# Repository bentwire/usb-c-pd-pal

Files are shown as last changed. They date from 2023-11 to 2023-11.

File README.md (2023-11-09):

# usb-c-pd-pal
100W USB C PD Power path with on board switches and current sensing.  Can take input from USB-C, Barell, or wire terminal, and output to wire terminal or USB-C.

This design can do up to 100W PD.  The switches and connectors are all rated for 5A, the max voltage is 21V so it can't do the extended power ranges.

There is a separate power path for both the 5V only and High Power paths.  The board is wired to be capable of both sink and source modes.

If you wish to make this board act as a source you will need to provide 5V to the 5V power path at the very least.

TODO:
Code forthcoming.
Still need to finish the layout.
Some parts won't be generally available until next year...

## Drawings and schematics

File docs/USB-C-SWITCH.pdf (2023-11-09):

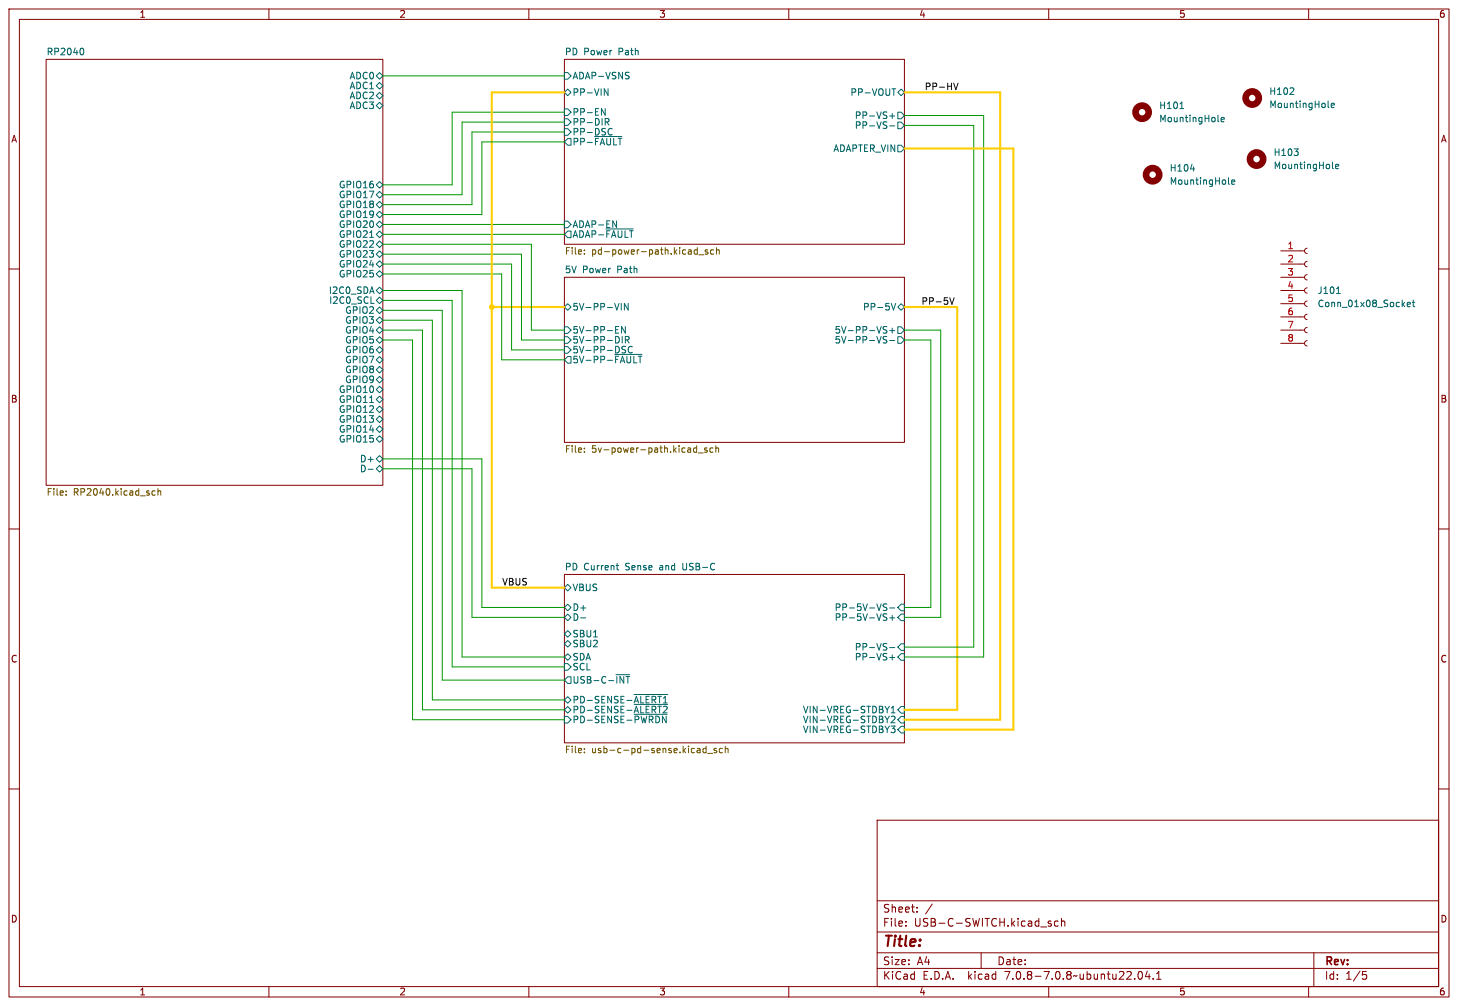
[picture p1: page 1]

PD Power Path File: pd-power-path.kicad_sch

ADAP-VSNS
PP-VOUT PP-VS+ PP-VS- PP-EN

PP-~{FAULT} PP-VIN

PP-DIR
ADAP-~{FAULT} PP-DSC

5V-PP-VS- 5V-PP-VIN

Id: 1/5 Title: File: USB-C-SWITCH.kicad_sch Sheet: / D- D+ GPIO10 GPIO9 GPIO8

File: usb-c-pd-sense.kicad_sch

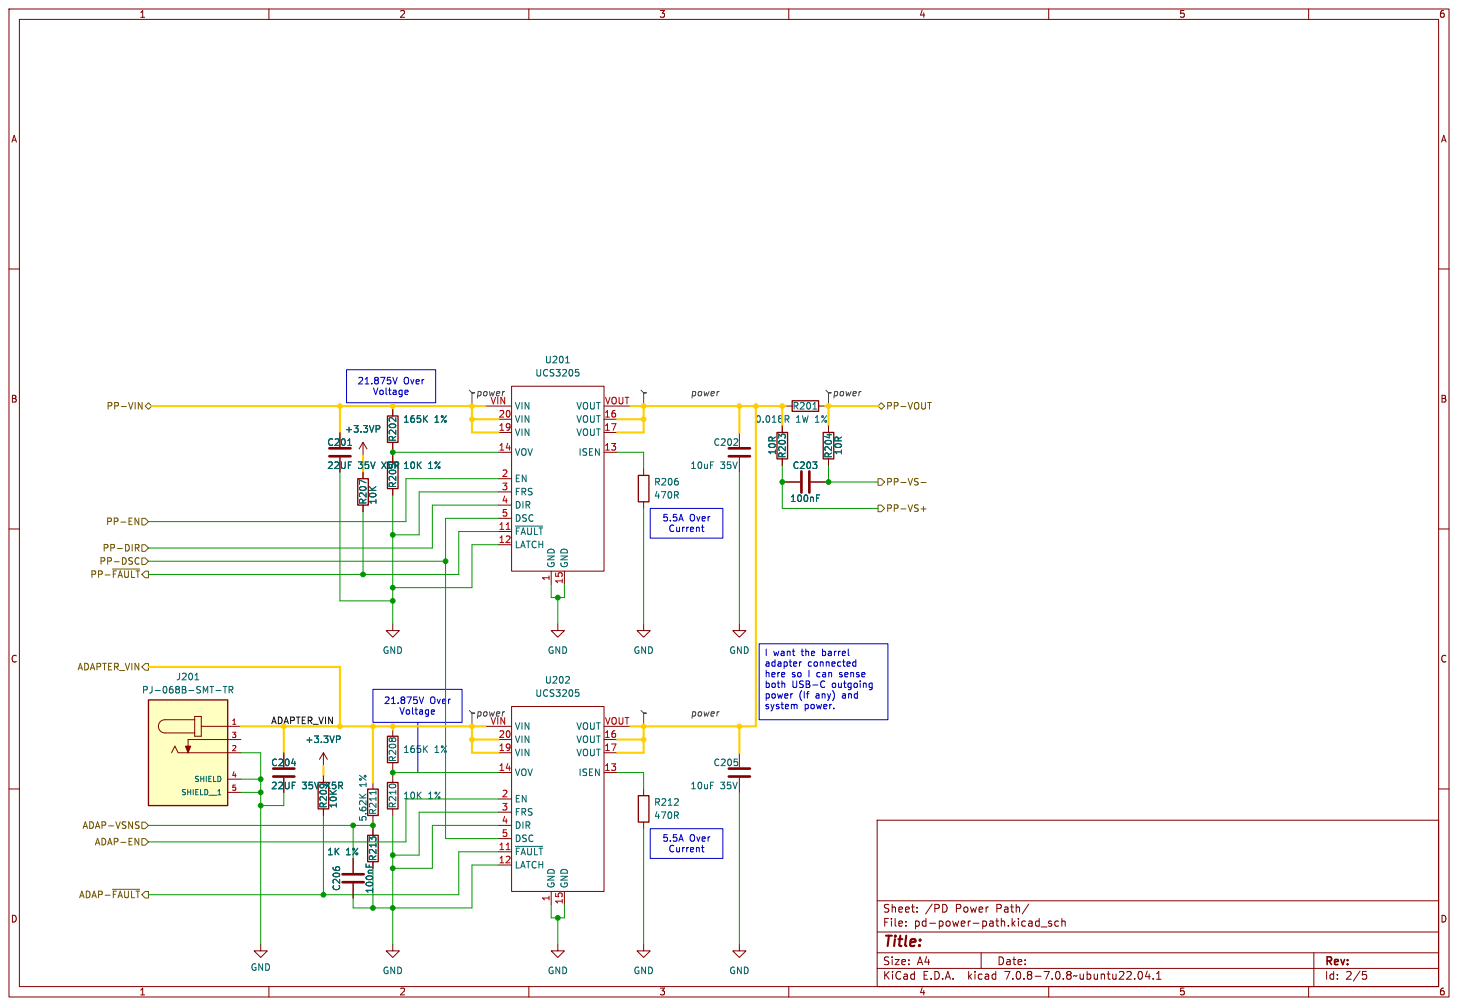
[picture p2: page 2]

system power. 21.875V Over Voltage

I want the barrel adapter connected

here so I can sense
both USB-C outgoing
power (If any) and

ADAP-VSNS
ADAP-~{FAULT} ADAP-EN

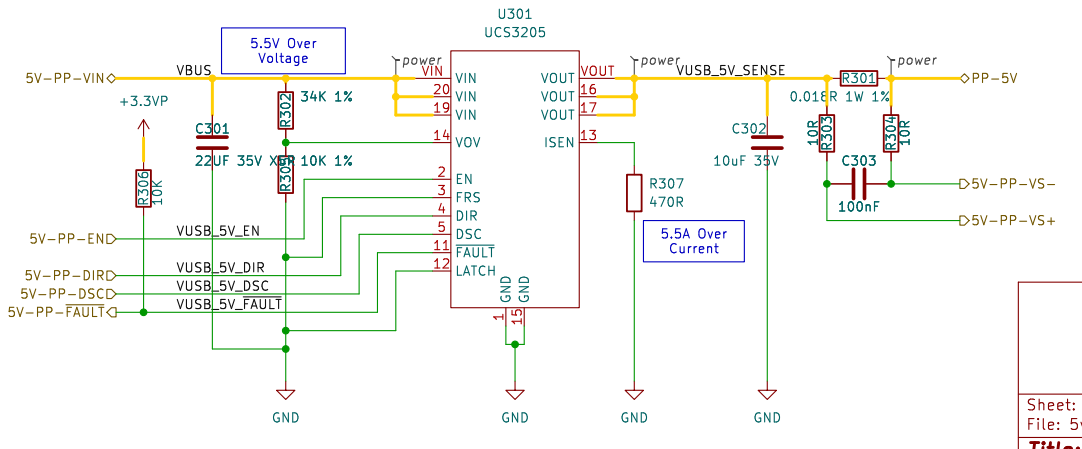
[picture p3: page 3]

5V-PP-~{FAULT} 5V-PP-EN

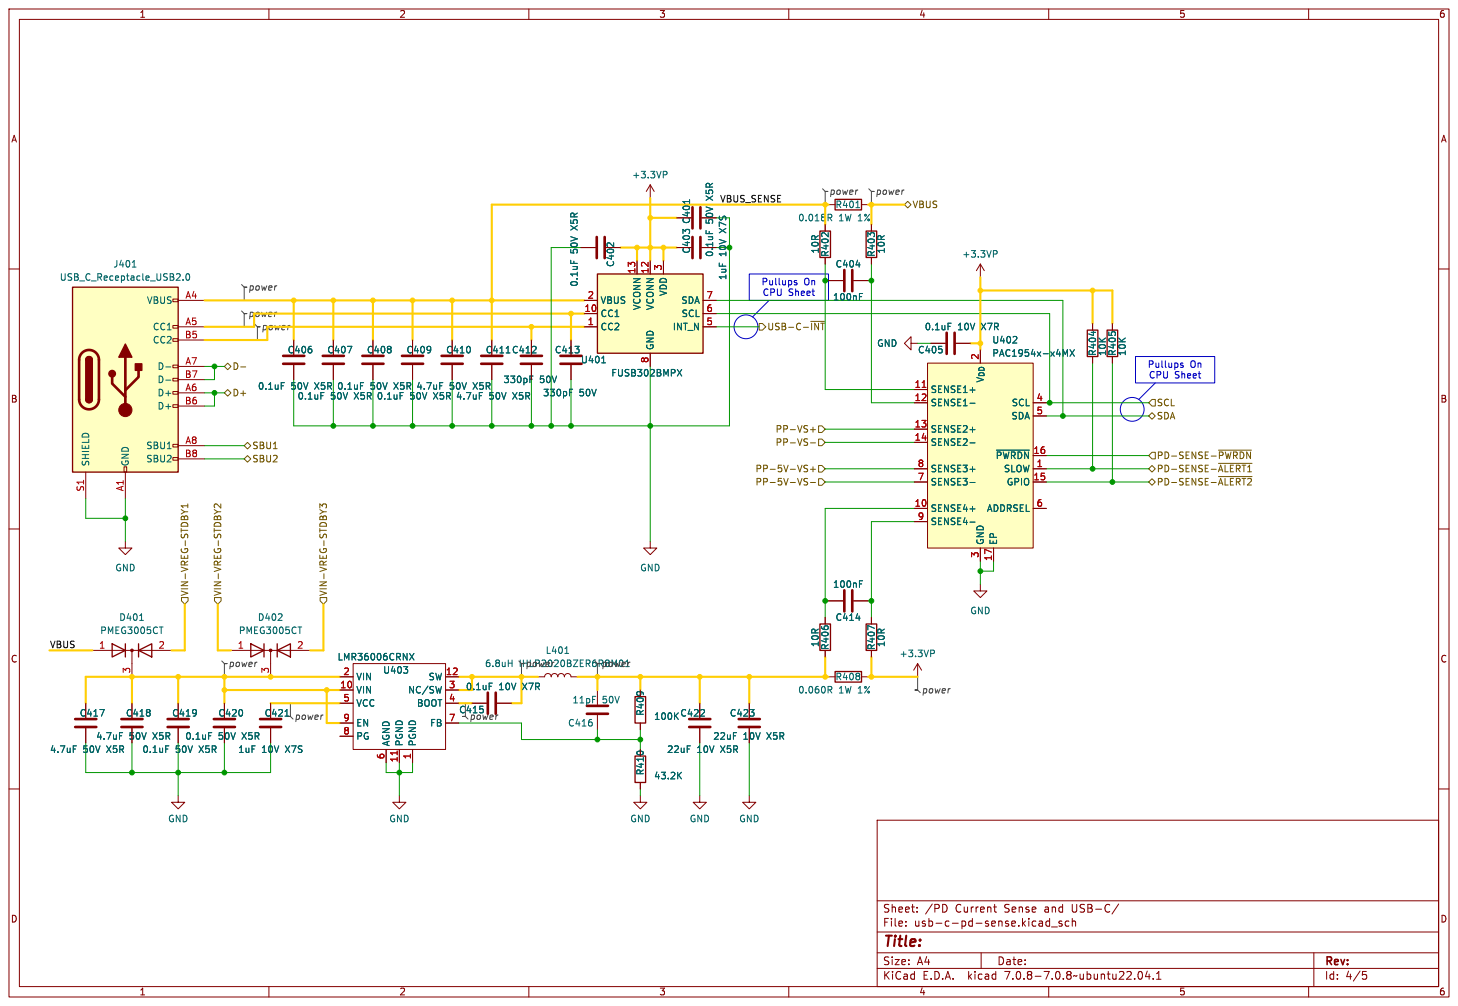
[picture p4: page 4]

3 D402 PMEG3005CT C401 0.1uF 50V X5R R402 10R
power power powerpower power power

Pullups On CPU Sheet Pullups On CPU Sheet C421

3 SCL 4 SDA 5 ADDRSEL 6 SENSE3- 7 SENSE3+ 8 SENSE4- 9 U402 PAC1954x-x4MX GND A1 VBUS A4 CC1 A5 D+ A6 D- A7 SBU1 A8 CC2 B5 D+ B6 D- B7 SBU2 B8 SHIELD S1

1 VIN 10 PGND 11 SW 12 VIN 2 NC/SW 3 BOOT 4 VCC 5 AGND

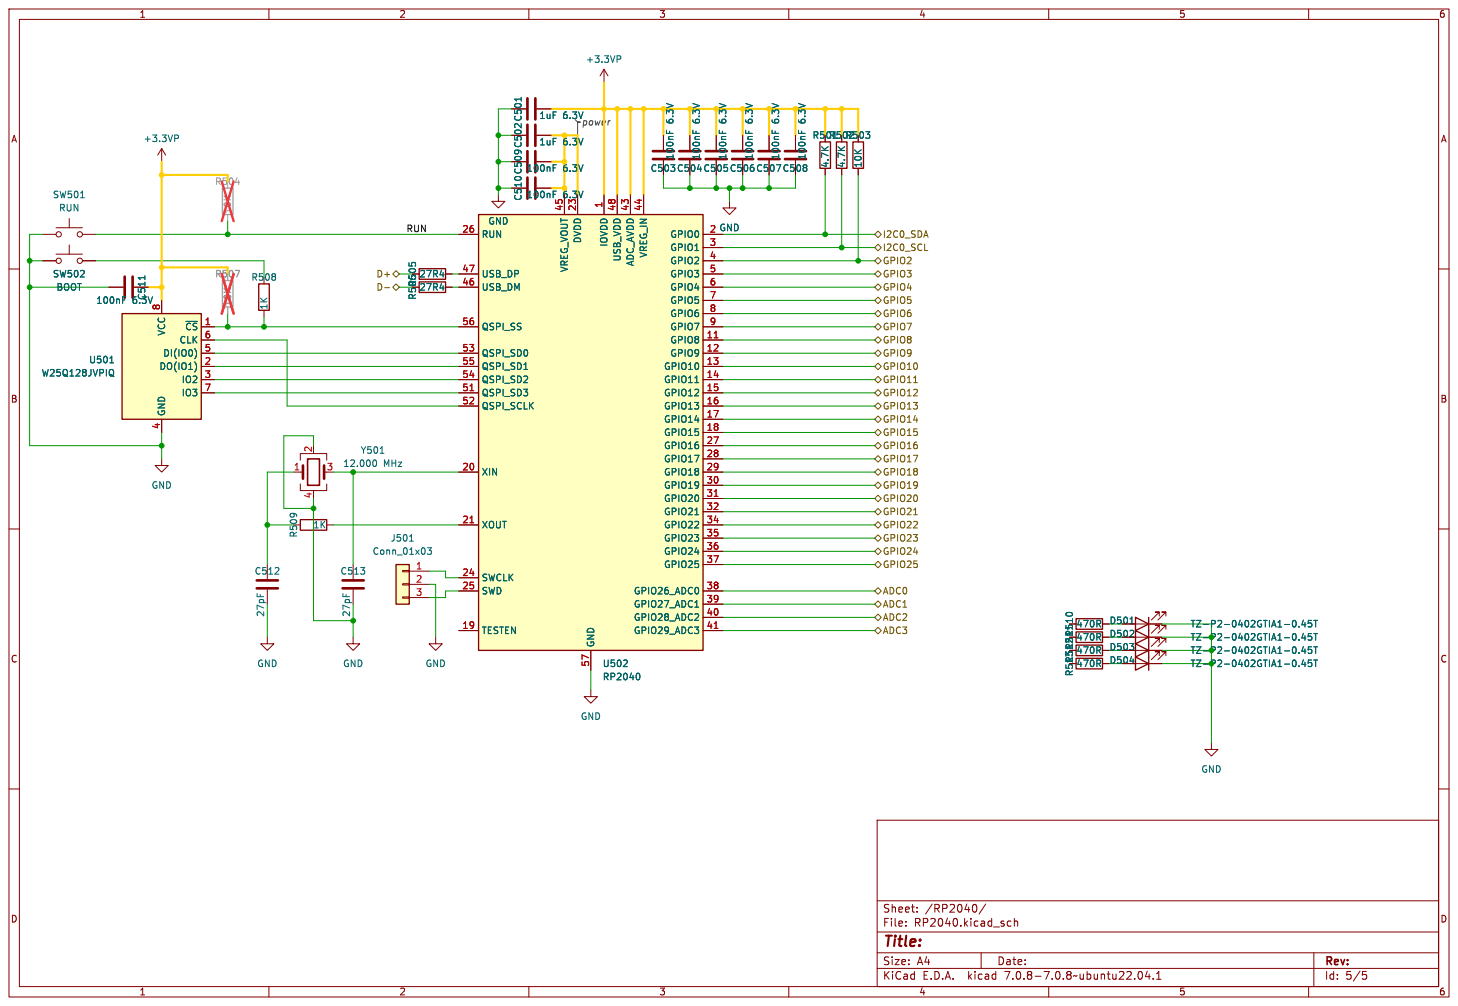
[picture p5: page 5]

1 GPIO8 11 GPIO9 12 GPIO10 13 GPIO11 14 GPIO12 15 GPIO13 16 GPIO14 17 GPIO15 18 TESTEN 19 GPIO0 2 XIN 20 XOUT 21 DVDD 23 SWCLK 24 SWD 25 RUN 26 GPIO16 27 GPIO17 28 GPIO18 29 GPIO1 3 GPIO19 30 GPIO20 31 GPIO21 32 GPIO22 34 GPIO23 35 GPIO24 36 GPIO25 37 GPIO26_ADC0 38 GPIO27_ADC1 39 GPIO2 4 GPIO28_ADC2 40 GPIO29_ADC3 41 ADC_AVDD 43 VREG_IN 44 VREG_VOUT 45 USB_DM 46 USB_DP 47 USB_VDD 48 GPIO3 5 QSPI_SD3 51 QSPI_SCLK 52 QSPI_SD0 53 QSPI_SD2 54 QSPI_SD1 55 QSPI_SS 56 GND 57 GPIO4 6 GPIO5 7 GPIO6 8 GPIO7 9C505 100nF C501 6.3V 1uF 6.3V C503 100nF 6.3V C504 100nF 6.3V R513 470R R511 470R R512 470R R510 470R

1 GPIO8 11 GPIO9 12 GPIO10 13 GPIO11 14 GPIO12 15 GPIO13 16 GPIO14 17 GPIO15 18 TESTEN 19 GPIO0 2 XIN 20 XOUT 21 DVDD 23 SWCLK 24 SWD 25 RUN 26 GPIO16 27 GPIO17 28 GPIO18 29 GPIO1 3 GPIO19 30 GPIO20 31 GPIO21 32 GPIO22 34 GPIO23 35 GPIO24 36 GPIO25 37 GPIO26_ADC0 38 GPIO27_ADC1 39 GPIO2 4 GPIO28_ADC2 40 GPIO29_ADC3 41 ADC_AVDD 43 VREG_IN 44 VREG_VOUT 45 USB_DM 46 USB_DP 47 USB_VDD 48 GPIO3 5 QSPI_SD3 51 QSPI_SCLK 52 QSPI_SD0 53 QSPI_SD2 54 QSPI_SD1 55 QSPI_SS 56 GND 57 GPIO4 6 GPIO5 7 GPIO6 8 GPIO7 9 U502 RP2040 GND

Id: 5/5 Title: File: RP2040.kicad_sch Sheet: /RP2040/

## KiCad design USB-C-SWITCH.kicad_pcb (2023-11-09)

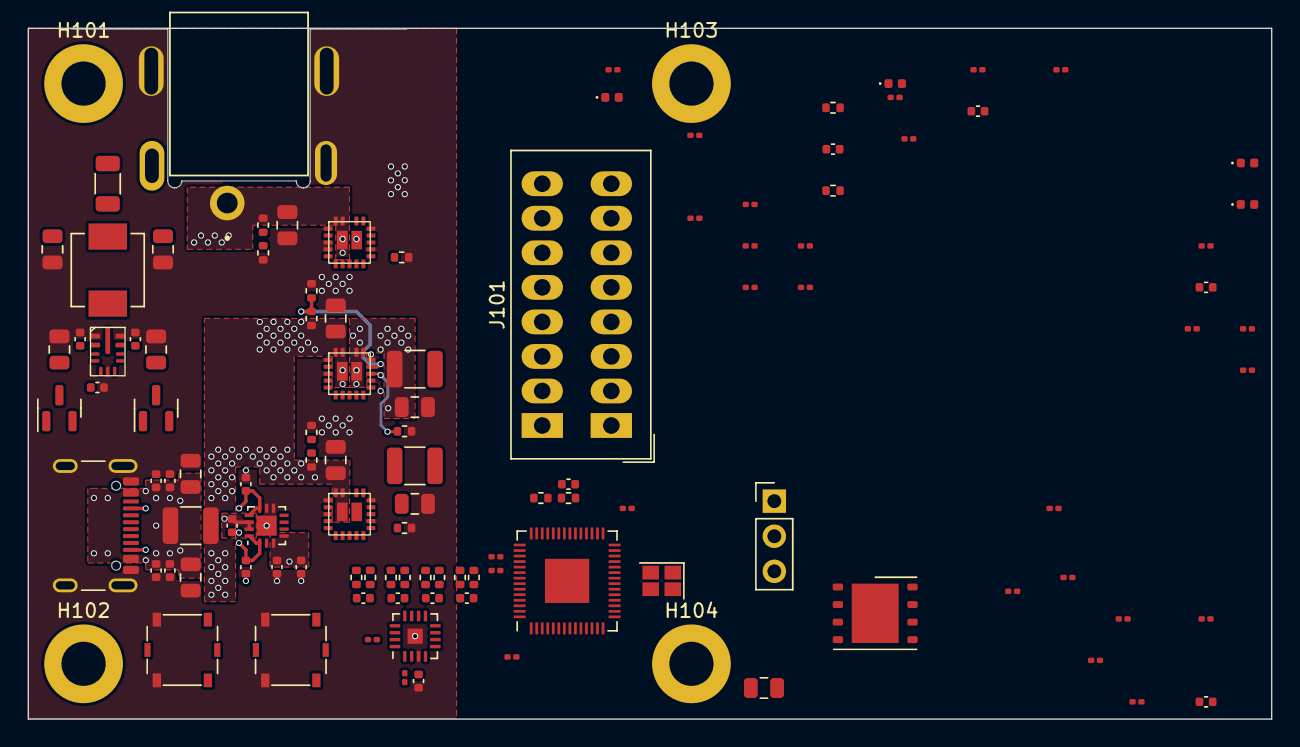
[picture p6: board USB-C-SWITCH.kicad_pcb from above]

Board: 4 copper layers, 90.0 x 50.0 mm, 114 parts (0 on the bottom side), 70 nets.

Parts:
C201, C204, C301: 22UF 35V X5R; C_0805_2012Metric
C202, C205, C302: 10uF 35V; C_0805_2012Metric
C203, C206, C303, C404, C414: 100nF; C_0402_1005Metric
C401, C402, C406, C407, C408, C409, C419, C420: 0.1uF 50V X5R; C_0402_1005Metric
C403, C421: 1uF 10V X7S; C_0402_1005Metric
C405, C415: 0.1uF 10V X7R; C_0402_1005Metric
C410, C411, C417, C418: 4.7uF 50V X5R; C_0805_2012Metric
C412, C413: 330pF 50V; C_0402_1005Metric
C416: 11pF 50V; C_0402_1005Metric
C422, C423: 22uF 10V X5R; C_0805_2012Metric
C501, C502: 1uF 6.3V; C_0402_1005Metric
C503, C504, C505, C506, C507, C508, C509, C510, C511: 100nF 6.3V; C_0201_0603Metric
C512, C513: 27pF; C_0201_0603Metric
D401, D402: PMEG3005CT; SOT-23
D501, D502, D503, D504: TZ-P2-0402GTIA1-0.45T; LED_0402_1005Metric
H101, H102, H103, H104: MountingHole; MountingHole_3.2mm_M3_ISO7380_Pad
J101: Conn_01x08_Socket; TerminalBlock_Phoenix_PTSM-0,5-8-2.5-H-THR_1x08_P2.50mm_Hor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
J201: PJ-068B-SMT-TR; CUI_PJ-068B-SMT-TR
J401: USB_C_Receptacle_USB2.0; USB_C_Receptacle_GCT_USB4105-xx-A_16P_TopMnt_Horizontal
J501: Conn_01x03; PinHeader_1x03_P2.54mm_Vertical
L401: 6.8uH IHLP2020BZER6R8M01; L_Vishay_IHLP-2020
R201, R301, R401: 0.018R 1W 1%; R_1210_3225Metric
R202, R208: 165K 1%; R_0402_1005Metric
R203, R204, R303, R304, R402, R403, R406, R407: 10R; R_0402_1005Metric
R205, R210, R305: 10K 1%; R_0402_1005Metric
R206, R212, R307: 470R; R_0402_1005Metric
R207, R209, R306, R404, R405, R503, R504, R507: 10K; R_0201_0603Metric
R211: 5.62K 1%; R_0402_1005Metric
R213: 1K 1%; R_0402_1005Metric
R302: 34K 1%; R_0402_1005Metric
R408: 0.060R 1W 1%; R_1206_3216Metric
R409: 100K; R_0402_1005Metric
R410: 43.2K; R_0402_1005Metric
R501, R502: 4.7K; R_0201_0603Metric
R505, R506: 27R4; R_0201_0603Metric
R508, R509: 1K; R_0201_0603Metric
R510, R511, R512, R513: 470R; R_0201_0603Metric
SW501: RUN; SW_SPST_Panasonic_EVQPL_3PL_5PL_PT_A15
SW502: BOOT; SW_SPST_Panasonic_EVQPL_3PL_5PL_PT_A15
U201, U202, U301: UCS3205; 19-VQFN-Q8A-3x3x0.9-2EP
U401: FUSB302BMPX; WQFN-14-1EP_2.5x2.5mm_P0.5mm_EP1.45x1.45mm
U402: PAC1954x-x4MX; VQFN-16-1EP_3x3mm_P0.5mm_EP1.1x1.1mm
U403: LMR36006CRNX; TI-RNX0012A-VQFN-HR
U501: W25Q128JVPIQ; WSON-8-1EP_6x5mm_P1.27mm_EP3.4x4.3mm
U502: RP2040; QFN-56-1EP_7x7mm_P0.4mm_EP3.2x3.2mm
Y501: 12.000 MHz; Crystal_SMD_EuroQuartz_X22-4Pin_2.5x2.0mm

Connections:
+3.3VP: C401.1, C402.1, C403.1, C405.2, C501.2, C503.2, C504.2, C505.2, C506.2, C507.2, C508.2, C511.1, R207.1, R209.1, R306.1, R404.1, R405.1, R407.1, R408.2, R501.1, R502.1, R503.1, R504.1, R507.1, U401.3 (VDD), U401.4 (VDD), U401.12 (VCONN), U401.13 (VCONN), U402.2 (V_{DD}), U501.8 (VCC), U502.1 (IOVDD), U502.10 (IOVDD), U502.22 (IOVDD), U502.33 (IOVDD), U502.42 (IOVDD), U502.43 (ADC_AVDD), U502.44 (VREG_IN), U502.48 (USB_VDD), U502.49 (IOVDD)
/5V Power Path/5V-PP-VS+: C303.1, R303.2, U402.8 (SENSE3+)
/5V Power Path/5V-PP-VS-: C303.2, R304.2, U402.7 (SENSE3-)
/5V Power Path/VUSB_5V_DIR: U301.4 (DIR), U502.35 (GPIO23)
/5V Power Path/VUSB_5V_DSC: U301.5 (DSC), U502.36 (GPIO24)
/5V Power Path/VUSB_5V_EN: U301.2 (EN), U502.34 (GPIO22)
/5V Power Path/VUSB_5V_SENSE: C302.1, R301.1, R303.1, U301.16 (VOUT), U301.17 (VOUT), U301.VOUT
/5V Power Path/VUSB_5V_~FAULT: R306.2, U301.11 (~FAULT), U502.37 (GPIO25)
/PD Current Sense and USB-C/D+: J401.A6 (D+), J401.B6 (D+), R505.1
/PD Current Sense and USB-C/D-: J401.A7 (D-), J401.B7 (D-), R506.1
/PD Current Sense and USB-C/PD-SENSE-~ALERT1: R404.2, U402.1 (SLOW), U502.5 (GPIO3)
/PD Current Sense and USB-C/PD-SENSE-~ALERT2: R405.2, U402.15 (GPIO), U502.6 (GPIO4)
/PD Current Sense and USB-C/PD-SENSE-~PWRDN: U402.16 (~PWRDN), U502.7 (GPIO5)
/PD Current Sense and USB-C/PP-VS+: C203.1, R203.2, U402.13 (SENSE2+)
/PD Current Sense and USB-C/PP-VS-: C203.2, R204.2, U402.14 (SENSE2-)
/PD Current Sense and USB-C/SCL: R502.2, U401.6 (SCL), U402.4 (SCL), U502.3 (GPIO1)
/PD Current Sense and USB-C/SDA: R501.2, U401.7 (SDA), U402.5 (SDA), U502.2 (GPIO0)
/PD Current Sense and USB-C/USB-C-~INT: R503.2, U401.5 (INT_N), U502.4 (GPIO2)
/PD Current Sense and USB-C/VBUS_SENSE: C406.1, C407.1, C408.1, C409.1, C410.1, C411.1, J401.A4 (VBUS), J401.A9 (VBUS), J401.B4 (VBUS), J401.B9 (VBUS), R401.1, R402.1, U401.2 (VBUS)
/PD Power Path/ADAP-EN: U202.2 (EN), U502.31 (GPIO20)
/PD Power Path/ADAP-VSNS: C206.2, R211.2, R213.1, U502.38 (GPIO26_ADC0)
/PD Power Path/ADAP-~FAULT: R209.2, U202.11 (~FAULT), U502.32 (GPIO21)
/PD Power Path/ADAPTER_VIN: C204.1, D402.2 (A), J201.1, R208.1, R211.1, U202.19 (VIN), U202.20 (VIN), U202.VIN
/PD Power Path/PP-DIR: U201.4 (DIR), U502.28 (GPIO17)
/PD Power Path/PP-DSC: U201.5 (DSC), U202.5 (DSC), U502.29 (GPIO18)
/PD Power Path/PP-EN: U201.2 (EN), U502.27 (GPIO16)
/PD Power Path/PP-~FAULT: R207.2, U201.11 (~FAULT), U502.30 (GPIO19)
/PP-5V: D401.2 (A), R301.2, R304.1
/PP-HV: D402.1 (A), R201.2, R204.1
/RP2040/RUN: R504.2, SW501.2, U502.26 (RUN)
/VBUS: C201.1, C301.1, D401.1 (A), R202.1, R302.1, R401.2, R403.1, U201.19 (VIN), U201.20 (VIN), U201.VIN, U301.19 (VIN), U301.20 (VIN), U301.VIN
GND: C201.2, C202.2, C204.2, C205.2, C206.1, C301.2, C302.2, C401.2, C402.2, C403.2, C405.1, C406.2, C407.2, C408.2, C409.2, C410.2, C411.2, C412.1, C413.1, C417.2, C418.2, C419.2, C420.2, C421.2, C422.1, C423.1, C501.1, C502.1, C503.1, C504.1, C505.1, C506.1, C507.1, C508.1, C509.1, C510.1, C511.2, C512.2, C513.2, D501.1 (K), D502.1 (K), D503.1 (K), D504.1 (K), J201.2, J201.4 (SHIELD), J201.5 (SHIELD__1), J401.A1 (GND), J401.A12 (GND), J401.B1 (GND), J401.B12 (GND), J401.S1 (SHIELD), J501.2, R205.2, R206.2, R210.2, R212.2, R213.2, R305.2, R307.2, R410.2, SW501.1, SW502.1, U201.1 (GND), U201.3 (FRS), U201.12 (LATCH), U201.15 (GND), U202.1 (GND), U202.3 (FRS), U202.4 (DIR), U202.12 (LATCH), U202.15 (GND), U301.1 (GND), U301.3 (FRS), U301.12 (LATCH), U301.15 (GND), U401.8 (GND), U401.9 (GND), U401.15 (GND), U402.3 (GND), U402.17 (EP), U403.1 (PGND), U403.6 (AGND), U403.11 (PGND), U501.4 (GND), U502.57 (GND), Y501.2, Y501.4
unnamed: C202.1, C205.1, R201.1, R203.1, U201.16 (VOUT), U201.17 (VOUT), U201.VOUT, U202.16 (VOUT), U202.17 (VOUT), U202.VOUT
unnamed: C416.2, C422.2, C423.2, L401.2, R406.1, R408.1, R409.1
unnamed: C512.1, R509.1, Y501.1
unnamed: C417.1, C418.1, C419.1, C420.1, D401.3 (K), D402.3 (K), U403.2 (VIN), U403.9 (EN), U403.10 (VIN)
unnamed: D501.2 (A), R510.2
unnamed: D502.2 (A), R511.2
unnamed: D503.2 (A), R512.2
unnamed: D504.2 (A), R513.2
unnamed: C413.2, J401.A5 (CC1), U401.10 (CC1), U401.11 (CC1)
unnamed: C412.2, J401.B5 (CC2), U401.1 (CC2), U401.14 (CC2)
unnamed: J501.1, U502.24 (SWCLK)
unnamed: J501.3, U502.25 (SWD)
unnamed: R508.1, SW502.2
unnamed: R206.1, U201.13 (ISEN)
unnamed: R202.2, R205.1, U201.14 (VOV)
unnamed: R212.1, U202.13 (ISEN)
unnamed: R208.2, R210.1, U202.14 (VOV)
unnamed: R307.1, U301.13 (ISEN)
unnamed: R302.2, R305.1, U301.14 (VOV)
unnamed: C404.1, R402.2, U402.11 (SENSE1+)
unnamed: C404.2, R403.2, U402.12 (SENSE1-)
unnamed: C414.1, R406.2, U402.10 (SENSE4+)
unnamed: C414.2, R407.2, U402.9 (SENSE4-)
unnamed: C415.1, U403.4 (BOOT)
unnamed: C416.1, R409.2, R410.1, U403.7 (FB)
unnamed: C415.2, L401.1, U403.3 (NC/SW), U403.12 (SW)
unnamed: C421.1, U403.5 (VCC)
unnamed: U501.6 (CLK), U502.52 (QSPI_SCLK)
unnamed: U501.5 (DI(IO0)), U502.53 (QSPI_SD0)
unnamed: U501.2 (DO(IO1)), U502.55 (QSPI_SD1)
unnamed: U501.3 (IO2), U502.54 (QSPI_SD2)
unnamed: U501.7 (IO3), U502.51 (QSPI_SD3)
unnamed: R507.2, R508.2, U501.1 (~CS), U502.56 (QSPI_SS)
unnamed: R506.2, U502.46 (USB_DM)
unnamed: R505.2, U502.47 (USB_DP)
unnamed: C502.2, C509.2, C510.2, U502.23 (DVDD), U502.45 (VREG_VOUT), U502.50 (DVDD)
unnamed: C513.1, U502.20 (XIN), Y501.3
unnamed: R509.2, U502.21 (XOUT)

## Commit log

2023-11-09 Initial import, Schematic 99% done, Some routing and placement done.
    [5v-power-path.kicad_sch, RP2040.kicad_sch, USB-C-SWITCH.kicad_pcb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]
2023-11-09 Add pdf/svg of schematic.
